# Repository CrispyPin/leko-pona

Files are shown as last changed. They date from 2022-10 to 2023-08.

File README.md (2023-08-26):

# leko pona
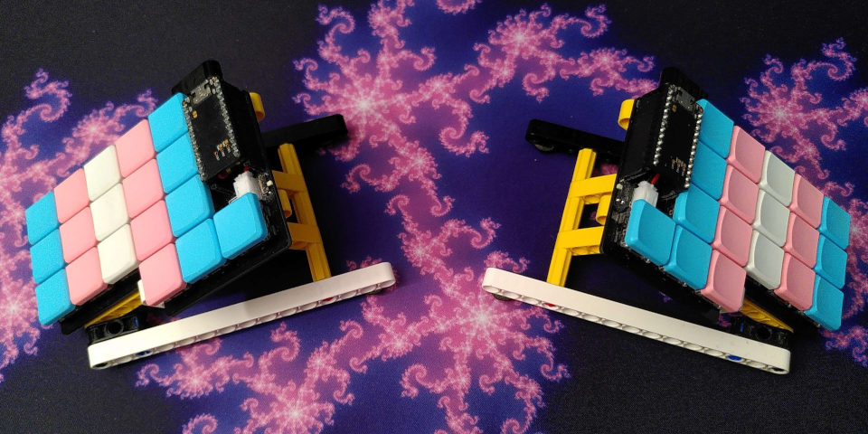
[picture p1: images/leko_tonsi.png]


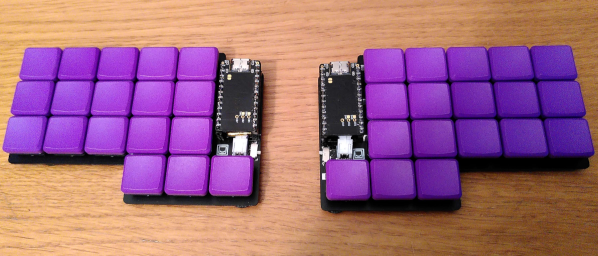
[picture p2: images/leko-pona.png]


## Related repos
- [ZMK config](https://github.com/CrispyPin/zmk-config/) (layout based on colemak-dh)
- [Ergogen config](https://github.com/CrispyPin/ergogen/) used to generate the pcb

## Parts list
- nice!nano x2
- 12 pin socket strips x4
- JST-PH battery connectors x2
- PCM12 power switch x2
- 3.7V 130mAh battery x2
- choc switches x36
- choc keycaps x36
- choc hotswap sockets x36 (optional)
- rubber feet (optional)

## Notes about assembly
- Solder pads for the reversible footprint should be soldered on the underside of the board if you want the back of the nice!nano facing up (like in the picture)
- The battery connector is slightly asymmetrical on the two halves, it should be clear from the outline on the silkscreen which way to put it
- If your batteries are small enough you can tuck them under the controllers
- You can use a permanent marker to get a clean look on the edges of the pcbs

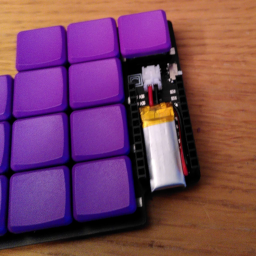
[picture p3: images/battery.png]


## LEGO tenting set
[Instructions](lego_tenting.md)

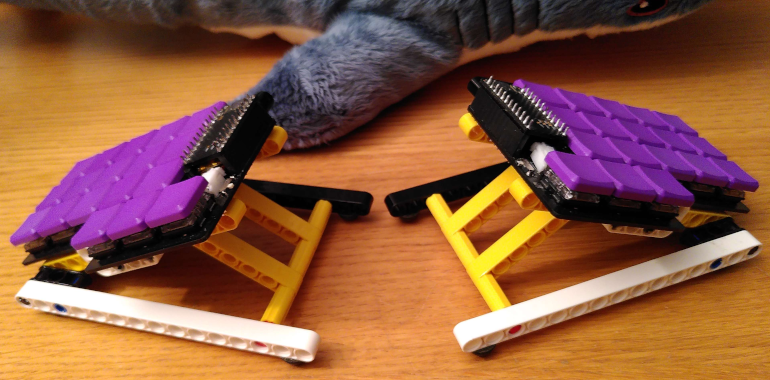
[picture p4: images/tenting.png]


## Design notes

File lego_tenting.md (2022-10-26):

# Lego tenting set for leko pona 1
## Parts
Parts required to build both halves:
- 4x 15u bars
- 4x 13u bars
- 4x 7u bars
- 2x 3u bars
- 4x small L bars
- 6x 2u axles
- 4x 3u axles
- 8x 4u axles
- 12x axle extender
- 6x friction pins
- 4x axle pins
- 4x 3u bars with axle holes
- 8x rubber feet

## Layout
Showing part layout for right tenting stand, repeat mirrored for other half.

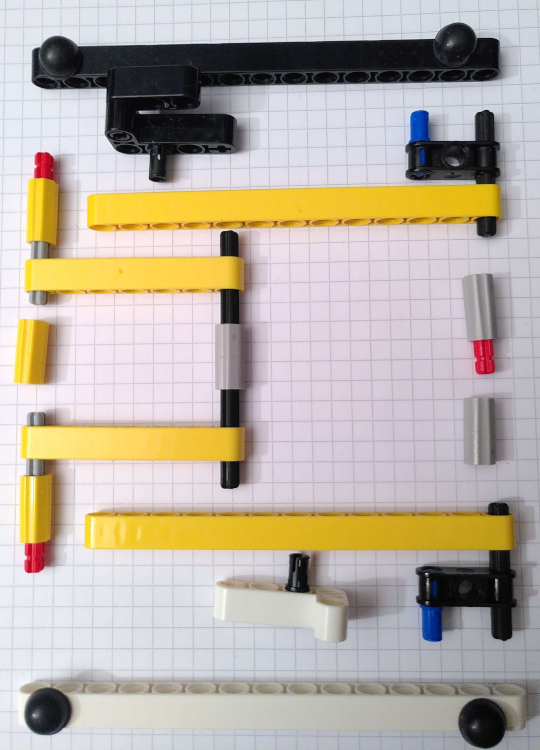
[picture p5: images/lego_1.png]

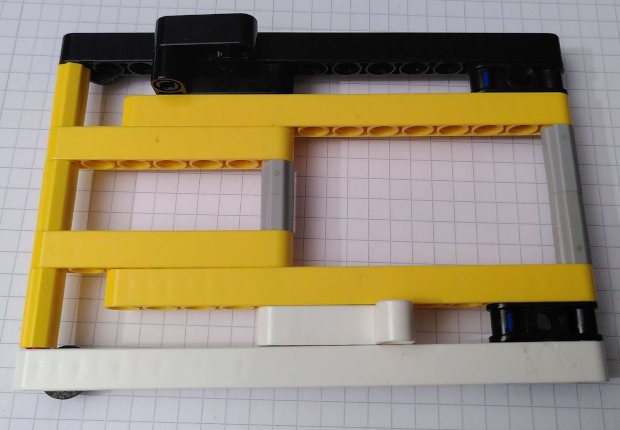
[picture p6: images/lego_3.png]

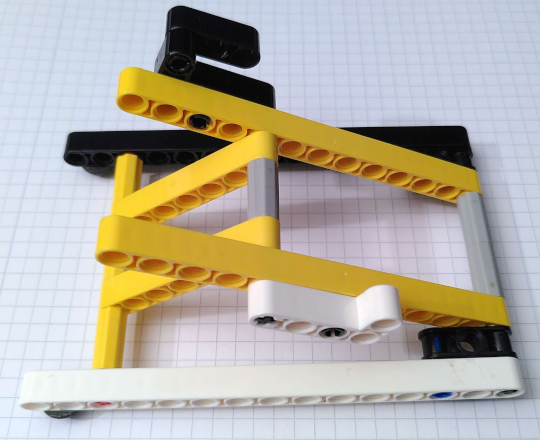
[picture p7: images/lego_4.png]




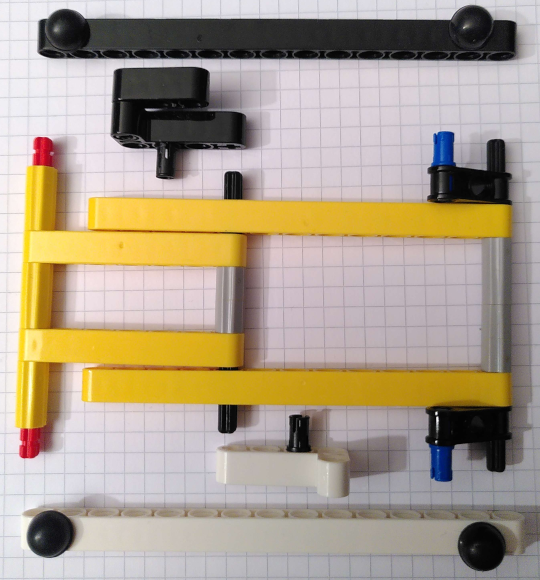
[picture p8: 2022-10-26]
images/lego_2.png

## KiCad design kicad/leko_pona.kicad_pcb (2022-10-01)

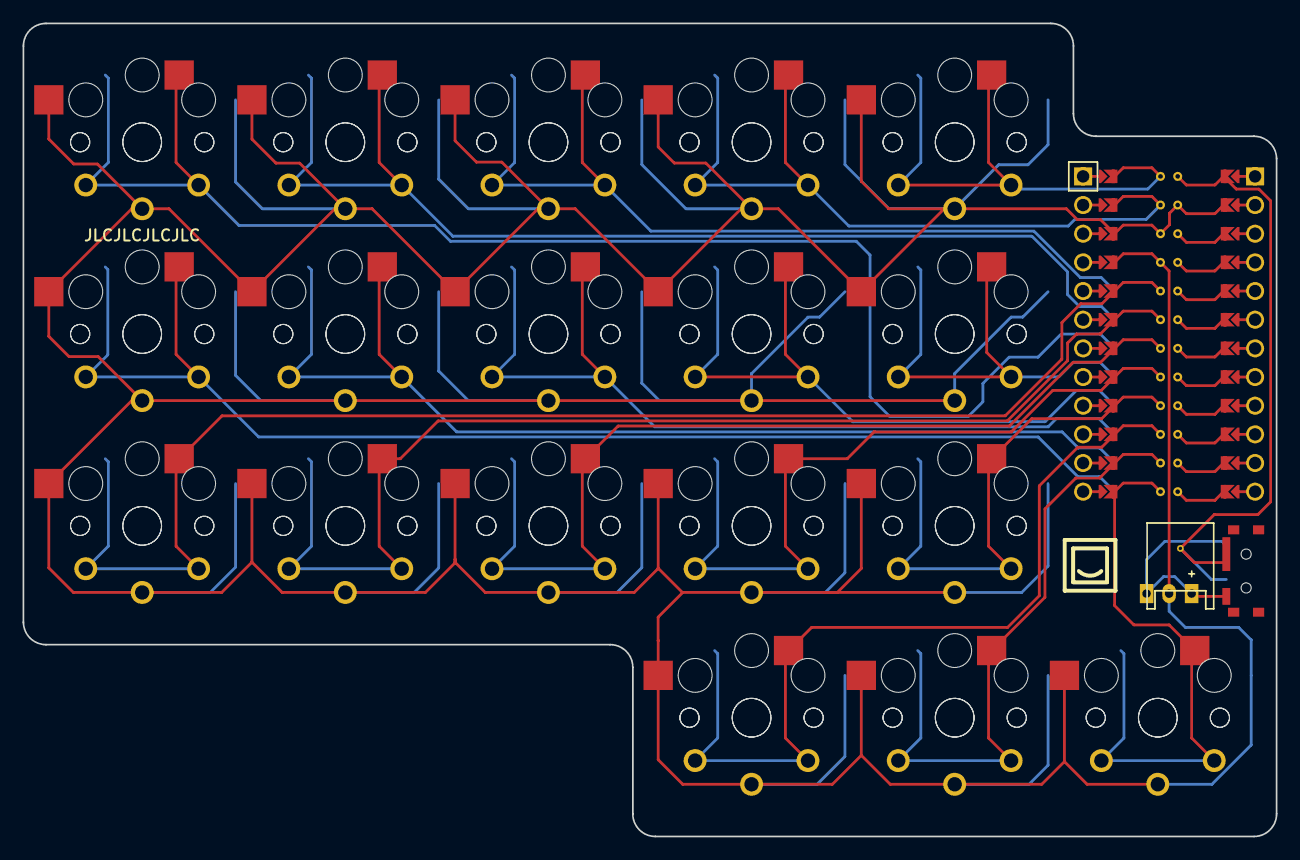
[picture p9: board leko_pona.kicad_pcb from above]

Board: 2 copper layers, 111.1 x 72.0 mm, 38 parts (0 on the bottom side), 20 nets.

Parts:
JST1: JST_PH_S2B-PH-K_02x2.00mm_Angled
MCU1: ProMicro
S1, S2, S3, S4, S5, S6, S7, S8, S9, S10, S11, S12, S13, S14, S15, S16, S17, S18, S19, S20, S21, S22, S23, S24, S25, S26, S27, S28, S29, S30, S31, S32, S33, S34, S35, S36: PG1350

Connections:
GND: JST1.2, MCU1.2, MCU1.21, MCU1.22, S1.2, S2.2, S3.2, S4.2, S5.2, S6.2, S7.2, S8.2, S9.2, S10.2, S11.2, S12.2, S13.2, S14.2, S15.2, S16.2, S17.2, S18.2, S19.2, S20.2, S21.2, S22.2, S23.2, S24.2, S25.2, S26.2, S27.2, S28.2, S29.2, S30.2, S31.2, S32.2, S33.2, S34.2, S35.2, S36.2
main_index_bottom: MCU1.17, S19.1, S20.1
main_index_home: MCU1.9, S21.1, S22.1
main_index_top: MCU1.23, S23.1, S24.1
main_inner_bottom: MCU1.16, S25.1, S26.1
main_inner_home: MCU1.8, S27.1, S28.1
main_inner_top: MCU1.24, S29.1, S30.1
main_middle_bottom: MCU1.18, S13.1, S14.1
main_middle_home: MCU1.10, S15.1, S16.1
main_middle_top: MCU1.5, S17.1, S18.1
main_pinky_bottom: MCU1.20, S1.1, S2.1
main_pinky_home: MCU1.12, S3.1, S4.1
main_pinky_top: MCU1.7, S5.1, S6.1
main_ring_bottom: MCU1.19, S7.1, S8.1
main_ring_home: MCU1.11, S9.1, S10.1
main_ring_top: MCU1.6, S11.1, S12.1
pos: JST1.1, JST1.3
thumb_middle_default: MCU1.14, S33.1, S34.1
thumb_reachy_default: MCU1.13, S35.1, S36.1
thumb_tucky_default: MCU1.15, S31.1, S32.1

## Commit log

2022-10-01 add pcb files
    [leko_pona-B_Cu.gbr, leko_pona-B_Mask.gbr, leko_pona-B_Paste.gbr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]
2022-10-01 move gerber zip
2022-10-21 Add part list and assembly notes to readme
2022-10-26 move kicad files to folder
    [leko_pona.kicad_pcb]
2024-04-15 add cad files for keyboard and case prototype
